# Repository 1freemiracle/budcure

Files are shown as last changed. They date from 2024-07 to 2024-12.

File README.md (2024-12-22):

# The Cannaster reinvisions the post-harvest workflow. The BudCureBox and Cannaster allows for automated control over the moisture content of the harvest, promising distinct differences in auroma and flavor. 

<div align="center">
BudCure machines
BudCure machines
</div>

## In the BudCureBox, you can estimate the moisture content by the weight loss due to evaporation. The weight is tracked from harvest and a target weight is calculated. This weight is used to know when to take the nugs off the branch and put into the Cannaster, when about 65% of the initial weight is lost.

<div align="center">
Inside BudCure Box
</div>

> The BudCure Box provides a stable environment for the buds to slowly dry. 

## The Cannaster takes mostly dry nugs and gets them to the perfect moisture content for canning. The vacuum brings moisture out from inside the nugs, drying them quickly and evenly to a precise moisture content. 

<div align="center">
inside the Cannaster
</div>
> The Cannaster dials in the moisture content of the buds in preparation for canning.

## The machines are built out of laser cut or 3D printed parts, and I have included up to date files on how to build one, including eagle PCB and fusion 360 files.

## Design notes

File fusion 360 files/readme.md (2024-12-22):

# Files for the 3D printed parts and laser cut panels. 
## Fusion 360 was used for the design work



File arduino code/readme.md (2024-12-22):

## The BudCure Box and Cannaster programs use a rotary encoder and OLED display to interact with users. 
# The BudCure Box and Cannaster use the Wemos D1 mini, and your able to connect to them on your phone via wifi.

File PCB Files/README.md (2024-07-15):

# EAGLE CAD FILES
## The BudCure Box and Cannaster utilize the Arduino Nano.

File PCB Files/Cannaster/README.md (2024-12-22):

# PCB files for the Cannaster
## 4 stepper motors plug directly into the board, with the L293D stepper driver chip. I'm also plugging into i2c humidity and pressure sensor, the BMP280 + AHT20, along with an OLED with rotary encoder display. The cannaster is powered by the wemos d1 mini. 
PCB rendering

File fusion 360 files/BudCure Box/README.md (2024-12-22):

door open
# The BudCure Box uses
##  laser cut panels and 3D printed parts. The box panels are held together with 3D printed slots bolted to the adjacent panel. One major design consideration is that the box has to be sealed from the outside humidity, so extra steps are taken to provide a sealed interior. The display is on the front door, and all the electronics are on the roof. The buds hang upside down from the load cell. There is a removable rack for loading the buds into the machine, I desgned some clips to hold the stems under spring pressure. It is designed to hold up to 1800 grams. 
Some design issues that have arrisen is that the rack is very sensitive, so all the wires above it had to be tied down. Also, the wires for the display limit the amount of travel of the door.

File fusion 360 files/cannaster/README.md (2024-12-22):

# Welcome to the Cannaster 
##

cannaster

The Cannaster is simple to build. The lid is the most complex part of the process, requiring a good enough seal to reach below 7psi. It has one port to accept 4 wires (to the i2c sensors) and a vacuum line. I have to use epoxy to seal the inside of the lid. The gasket that seals the baine marie to the lid is made from pourable silicon. The gasket is poured directly into the lid. The lid is driven by 4 stepper motors, turning a screw with just enough torque to push down the lid for a good enough seal to start pressurizing the pot. 

The baine marie has an insert that helps keep the buds seperated, made from extruded plexiglass and cut on the laser cutter.

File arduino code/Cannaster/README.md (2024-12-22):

# The Cannaster
## Super convenient way to get nugs to the perfect moisture content for canning
The cannaster uses a combination pressure, humidity, and temperature sensor to monitor the conditions inside the baine marie. A voltage converter converts the 3.3v of the D1 mini to 5v that the L293D chip uses to drive the stepper motors. 
### The Cannaster currently uses a timer to turn on the pump, and also a maximum rh level. So that you can set the pump to come on every 1.5 hours and the rh set at 80%, then the pump will turn on less and less until it only turns on every 1.5 hours. The cannaster also uses wifi to display data about the current drying states (well displaying it is a work in progress, but you can download the data from the sensors).

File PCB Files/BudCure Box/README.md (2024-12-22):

# PCB for the BudCure Box
## The BudCure Box pcb utilizes two mosfets, OLED/rotary encoder, i2c humidity sensor, load cell (with hx711), and a one wire temperature sensor for the TEC. 12V power runs the TEC and the fan while a 5v regulator supplies the Wemos. 
pcb image

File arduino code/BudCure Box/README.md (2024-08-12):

# The BudCure Box program files (Arduino IDE)
## The BudCure uses two mosfets to switch the thermoelectric device `TEC` and the exauhst fan. It reads from two sensors, one is a temperature probe (one wire 'dallas temperature sensor') plugged into the TEC, and a 'DHT22' temp/humidity sensor. I'm using a 'WEMOS D1 MINI' for the processor, using every pin except A0 (the single analog pin). I'm using interrupts to manage the rotary encoder with integrated pushbutton. Memory is also used to record various data.
To make the load cell more accurate (due to drift of the readings) I implimented a scheme where you remove the tray to tare out the drift and then replace the tray to get the correct weight readings. 
### Using the OLED display and the rotary encoder you can scroll through several options. You start with calibrating the scale (without the tray attached) with the calibrate option. That option puts in the weight of the tray into memory. You would then load up the tray with plant material and then use option "new weight" to record the starting initial wieght into memory. Then you would turn on either the fan or the TEC to keep the humidity down. As the material dries you keep recording new weights to track moisture loss.

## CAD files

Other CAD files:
fusion 360 files/cannaster/Arduinana_finale v42.f3z

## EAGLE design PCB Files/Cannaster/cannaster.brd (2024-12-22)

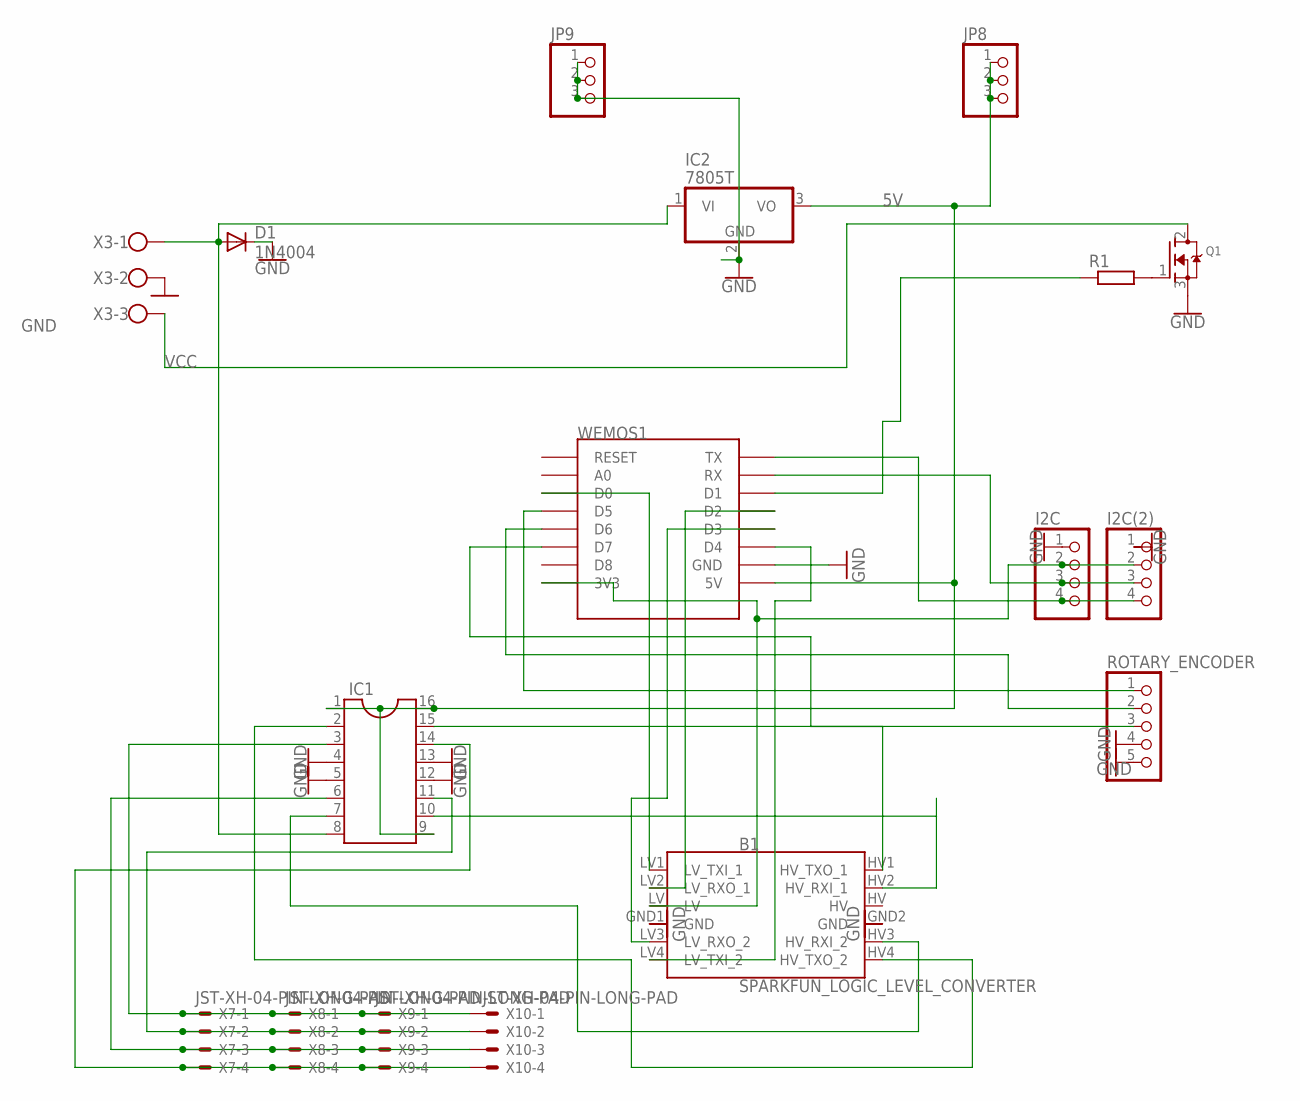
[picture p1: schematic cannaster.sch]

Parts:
B1: SPARKFUN_LOGIC_LEVEL_CONVERTER
D1: 1N4004; DO41-10
I2C, I2C(2): PINHD-1X4; 1X04
IC1: DIL16
IC2: 7805T; TO220H
JP8, JP9: PINHD-1X3; 1X03
Q1: MOSFET-NGDS_TO220V; TO220V
R1: R-EU_0207/7; 0207/7
ROTARY_ENCODER: PINHD-1X5; 1X05
WEMOS1: WEMOS-D1-MINI
X3: W237-103
X7, X8, X9, X10: JST-XH-04-PIN-LONG-PAD; JST-XH-04-PACKAGE-LONG-PAD

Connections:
5V: IC1.1, IC1.9, IC1.16, IC2.3 (VO), JP8.1, JP8.2, JP8.3, WEMOS1.5V
GND: B1.GND1 (GND), B1.GND2 (GND), D1.C, I2C.1, I2C(2).1, IC1.4, IC1.5, IC1.12, IC1.13, IC2.2 (GND), JP9.1, JP9.2, JP9.3, Q1.3 (S), ROTARY_ENCODER.4, ROTARY_ENCODER.5, WEMOS1.GND, X3.2
HV: B1.HV
unnamed: IC1.3, X7.1, X8.1, X9.1, X10.1
unnamed: IC1.11, X7.2, X8.2, X9.2, X10.2
unnamed: B1.HV1 (HV_TXO_1), IC1.15
unnamed: IC1.14, X7.4, X8.4, X9.4, X10.4
unnamed: B1.LV1 (LV_TXI_1), WEMOS1.D0
unnamed: Q1.2 (D), X3.3
unnamed: I2C.4, I2C(2).4, WEMOS1.TX
unnamed: I2C.3, I2C(2).3, WEMOS1.RX
unnamed: B1.LV2 (LV_RXO_1), WEMOS1.D2
unnamed: Q1.1 (G), R1.2
unnamed: B1.LV3 (LV_RXO_2), WEMOS1.D3
unnamed: B1.LV4 (LV_TXI_2), WEMOS1.D4
unnamed: ROTARY_ENCODER.1, WEMOS1.D5
unnamed: ROTARY_ENCODER.2, WEMOS1.D6
unnamed: ROTARY_ENCODER.3, WEMOS1.D7
unnamed: R1.1, WEMOS1.D1
unnamed: B1.LV, I2C.2, I2C(2).2, WEMOS1.3V3
unnamed: B1.HV2 (HV_RXI_1), IC1.10
unnamed: B1.HV3 (HV_RXI_2), IC1.7
unnamed: B1.HV4 (HV_TXO_2), IC1.2
unnamed: IC1.6, X7.3, X8.3, X9.3, X10.3
VCC: D1.A, IC1.8, IC2.1 (VI), X3.1

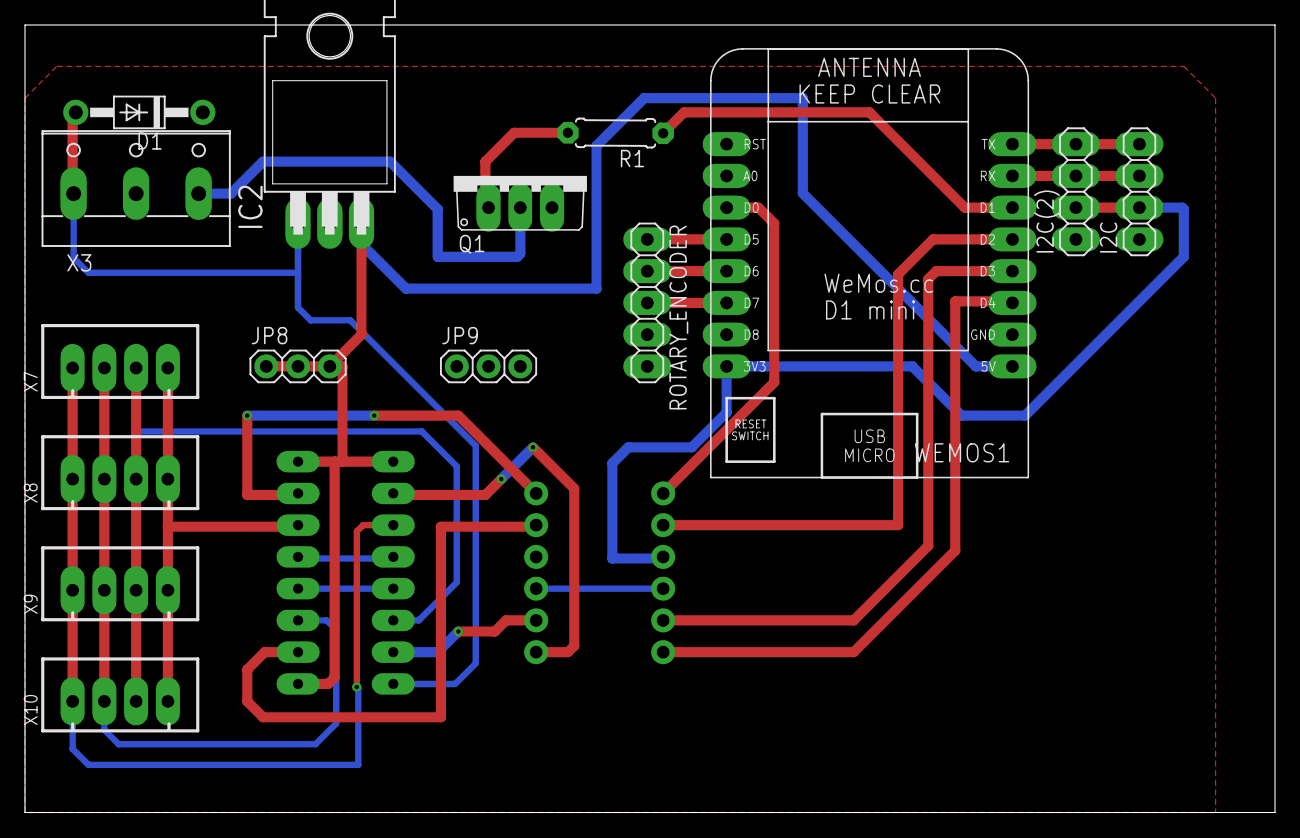
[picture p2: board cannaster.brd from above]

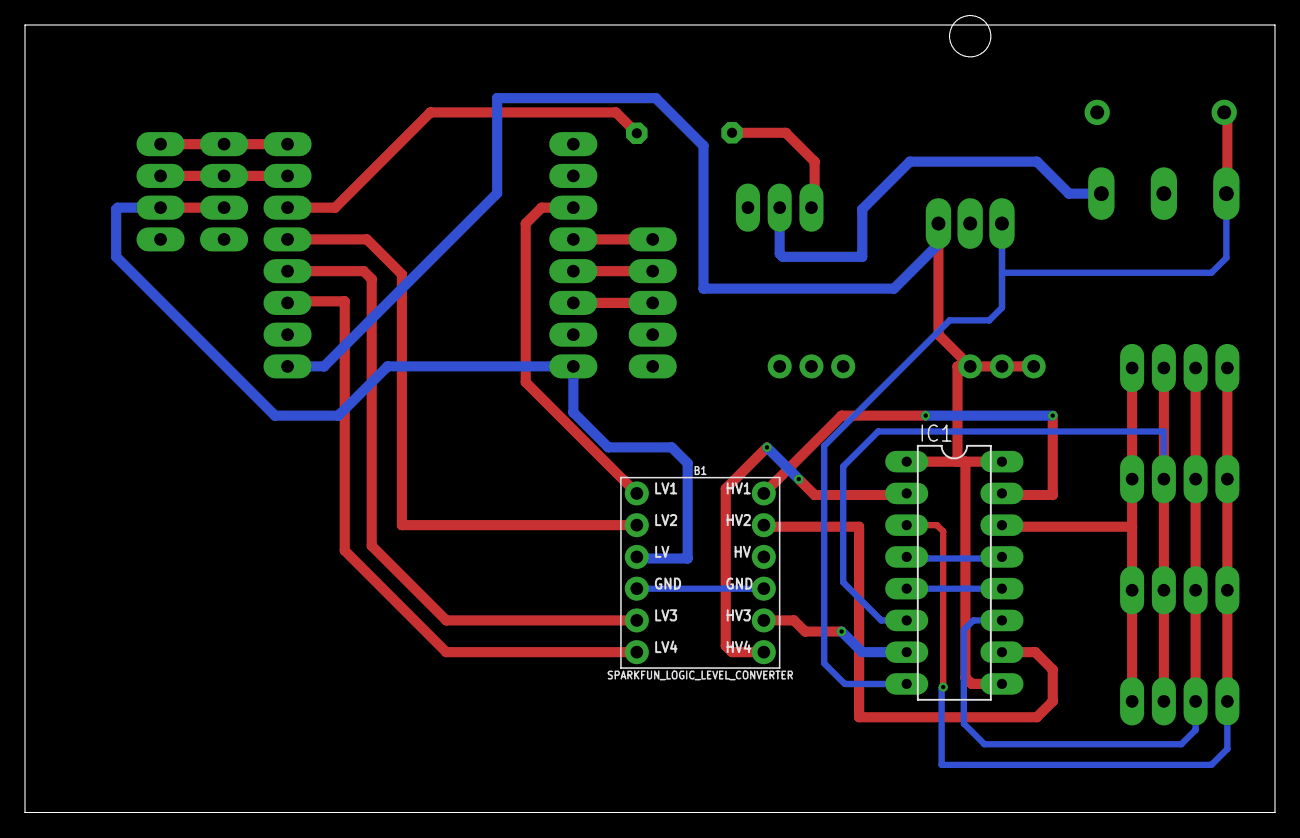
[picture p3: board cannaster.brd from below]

Board: 2 copper layers, 100.0 x 63.0 mm, 17 parts (2 on the bottom side), 24 nets.

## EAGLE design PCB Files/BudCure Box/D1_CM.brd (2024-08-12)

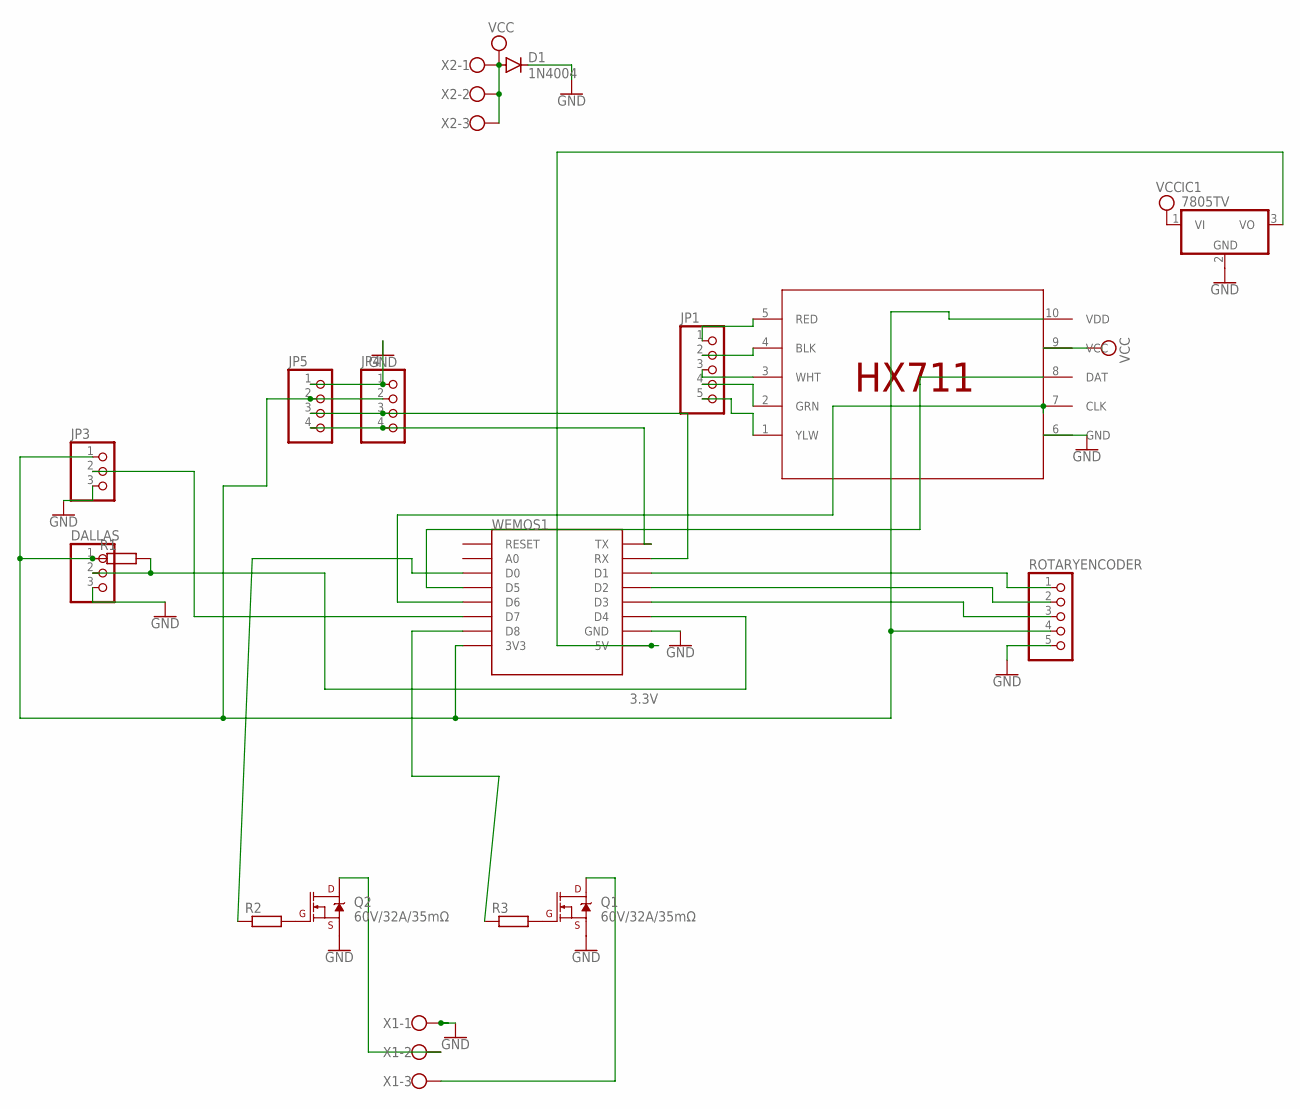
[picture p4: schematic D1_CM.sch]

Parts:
D1: 1N4004; DO41-10
DALLAS: PINHD-1X3; 1X03
IC1: 7805TV; TO220V
JP1: PINHD-1X5; 1X05
JP3: PINHD-1X3; 1X03
JP4, JP5: PINHD-1X4; 1X04
Q1, Q2: 60V/32A/35mΩ; TO220V
R1, R2, R3: R-EU_0207/7; 0207/7
ROTARYENCODER: PINHD-1X5; 1X05
U$1: DEVICY; FOOTSY
WEMOS1: WEMOS-D1-MINI
X1, X2: W237-103

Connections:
3.3V: DALLAS.1, JP3.1, JP4.2, JP5.2, R1.1, ROTARYENCODER.4, U$1.10 (VDD), WEMOS1.3V3
GND: D1.C, DALLAS.3, IC1.2 (GND), JP3.3, JP4.1, JP5.1, Q1.3 (S), Q2.3 (S), ROTARYENCODER.5, U$1.6 (GND), WEMOS1.GND, X1.1
unnamed: JP1.1, U$1.5 (RED)
unnamed: JP1.2, U$1.4 (BLK)
unnamed: JP1.3, U$1.3 (WHT)
unnamed: JP1.4, U$1.2 (GRN)
unnamed: JP1.5, U$1.1 (YLW)
unnamed: DALLAS.2, R1.2, WEMOS1.D4
unnamed: Q2.1 (G), R2.2
unnamed: JP4.3, JP5.3, WEMOS1.RX
unnamed: JP4.4, JP5.4, WEMOS1.TX
unnamed: Q1.1 (G), R3.2
unnamed: ROTARYENCODER.2, WEMOS1.D2
unnamed: ROTARYENCODER.1, WEMOS1.D1
unnamed: R2.1, WEMOS1.D0
unnamed: R3.1, WEMOS1.D8
unnamed: Q2.2 (D), X1.2
unnamed: Q1.2 (D), X1.3
unnamed: U$1.8 (DAT), WEMOS1.D5
unnamed: U$1.7 (CLK), WEMOS1.D6
unnamed: JP3.2, WEMOS1.D7
unnamed: ROTARYENCODER.3, WEMOS1.D3
unnamed: IC1.3 (VO), WEMOS1.5V
VCC: D1.A, IC1.1 (VI), U$1.9 (VCC), X2.1, X2.2, X2.3

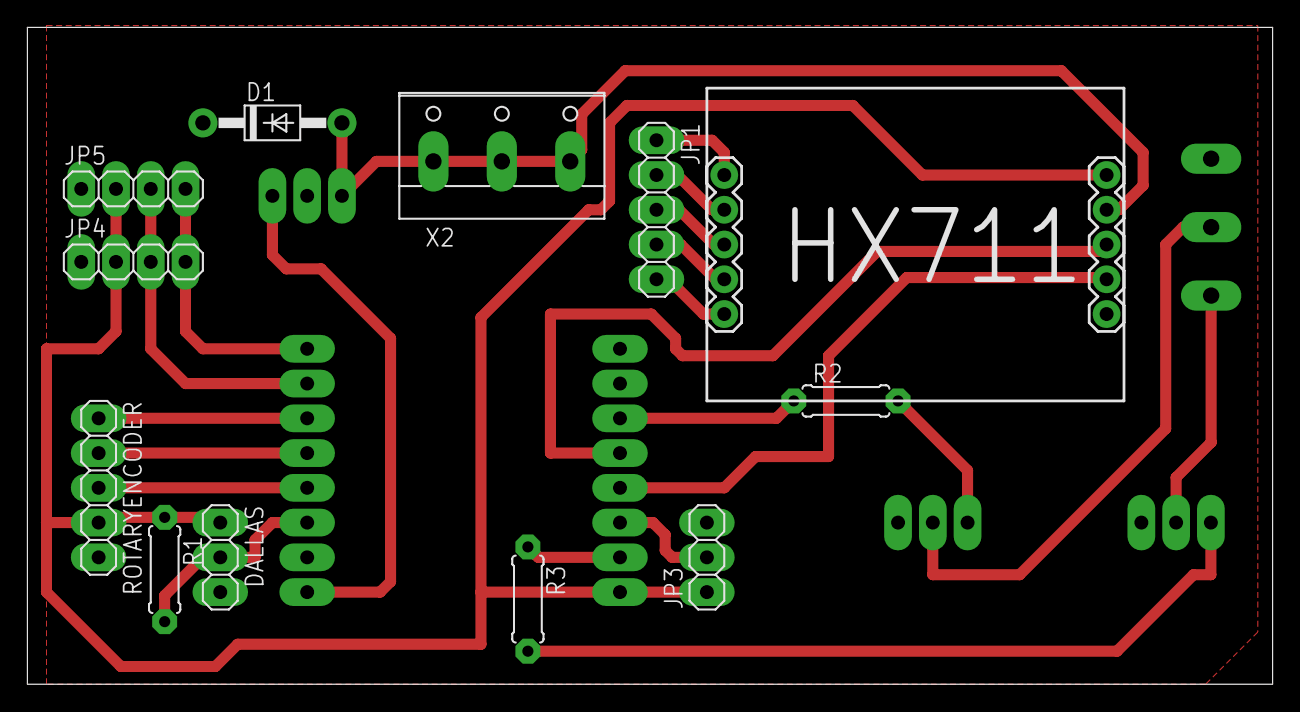
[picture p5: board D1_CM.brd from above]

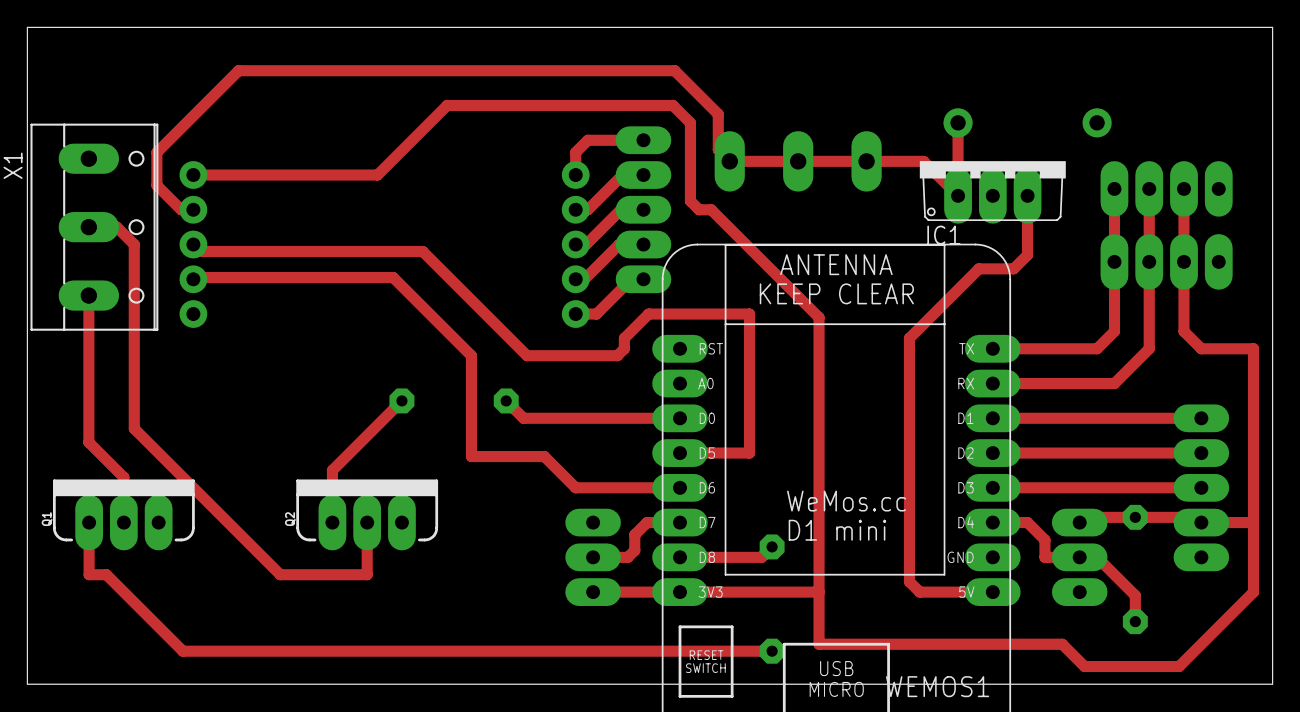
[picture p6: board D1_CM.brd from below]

Board: 2 copper layers, 91.0 x 48.0 mm, 17 parts (5 on the bottom side), 24 nets.

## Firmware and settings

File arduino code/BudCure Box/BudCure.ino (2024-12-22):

#include <Wire.h>              
#include "SSD1306Wire.h"       
#include <OneWire.h>
#include <DallasTemperature.h>
#include "ESPRotary.h"
#include "Ticker.h"
#include "DHT_Async.h"
#include <HX711_ADC.h>
#include <EEPROM.h>
#include <ESP8266WiFi.h>
#include <ESP8266WebServer.h>
#include <FS.h>  

#define DHT_SENSOR_TYPE DHT_TYPE_22
#define DHT_SENSOR_PIN D7
#define ROTARY_PIN1 D2
#define ROTARY_PIN2 D1
#define ENCODER_SWITCH_PIN D3
#define ONE_WIRE_BUS D4
#define FAN_PIN 16
#define TEC_PIN 15
#define HX711_dout D5 
#define HX711_sck D6
////////////////////////////////////////////////////////server
const char* targetSSID = "G8X"; // Your Wi-Fi SSID
const char* password = "6669inchs"; // Replace with your Wi-Fi password
ESP8266WebServer server(80);

////////////////////////////////////////////////////////loadcell
#define CALIBRATE_ADDRESS 0 //STATIC
#define TARE_ADDRESS 10 //STATIC
#define TRAY_ADDRESS 20 //STATIC
#define FANPROGRAM_ADDRESS 30 //booleen
#define TECPROGRAM_ADDRESS 32 //booleen
#define FANCYCLE_ADDRESS 35 //STATIC
#define FANDURATION_ADDRESS 40 //STATIC 
#define HUMIDITY_ADDRESS 45 //STATIC
#define FROSTY_ADDRESS 50 //STATIC
#define EVENT_ADDRESS 100 //DECIMAL NUMBER
#define TEMP_ADDRESS 300 //STORES AN ARRAY
#define WEIGHT_ADDRESS 200 //STORES AN ARRAY
float calibrationValue; 
int eventCount = 0; //track how many elements are in the weights array

DHT_Async dht_sensor(DHT_SENSOR_PIN, DHT_SENSOR_TYPE);
/////////////////////////////////////////////////////////Rotary Encoder
#define CLICKS_PER_STEP 2
#define MIN_POS         0
#define MAX_POS         10
#define START_POS       1
#define INCREMENT       1   
ESPRotary r;
Ticker t;
bool updateHomeScreen = false;  // Flag to trigger home screen update
/////////////////////////////////////////////////////////////Display
SSD1306Wire *display;

OneWire oneWire(ONE_WIRE_BUS);
DallasTemperature sensors(&oneWire);
DeviceAddress insideThermometer = { 0x28, 0x2E, 0x50, 0x57, 0x04, 0xE1, 0x3C, 0x42 };
HX711_ADC LoadCell(HX711_dout, HX711_sck);
/////////////////////////////////////////////////////////////////Weight Program
float loadData; //value from getData()
float trayWeight;
long storedTareValue; 
float weights[99]; 
float temps[99];
float weight;
//////////////////////////////////////////////////////////////////Sensor Data
float temperature; //temp of the box
float humidity;
float humidityThresholdOn = 75.0;  // Humidity level to turn the fan on
float humidityThresholdOff = 65.0; // Humidity level to turn the fan off
float tempC; //temp of the probe
bool flagData = true;
unsigned long seconds;
unsigned long minutes;
unsigned long hours;
//////////////////////////////////////////////////////Rotary Program
volatile bool interruptFlag = false; 
int lastPosition = 1; 
bool moved = false;
int position = 1; //position of the rotary encoder
int debounce = 50; //for the encoder pushbutton

void IRAM_ATTR handleInterrupt() {
  interruptFlag = true;
}
/////////////////////////////////////////////////////////////////////////////////////////////////////////////programs
int fanCyclesPerHour = 4; // Fan turns on this many times per fanCycleInterval
int fanOnDuration;   // length of time in seconds the fan stays on
int fanStartMinute = 0;  // Variable to store the minute when the fan was turned on
int fanCycleInterval;   // Used to calculate time inbetween fan starts
float humidities;
float frosty = -10;
int pwmTec = 0; // for setting the tec mosfet 
///////////////////////////////////////////////////////////////////////////////////////////////////////////////routing 
bool fanGram = false; //toggles in fan display so to keep the fanProgram current in the loop, saved to eeprom in case of reset
bool fanState = false; //used in fan program
bool tecGram = false;

const int MAX_DEVICES = 10;
String devicesOn[MAX_DEVICES];
int deviceCount = 0;

float dewPoint;

void setup() {
  pinMode(1, FUNCTION_3);
  pinMode(3, FUNCTION_3);
  pinMode(ENCODER_SWITCH_PIN, INPUT_PULLUP);
  pinMode(FAN_PIN, OUTPUT);
  pinMode(TEC_PIN, OUTPUT);
  attachInterrupt(digitalPinToInterrupt(ENCODER_SWITCH_PIN), handleInterrupt, FALLING);
  //display
  display = new SSD1306Wire(0x3c, 1, 3);
  display->init();
  display->flipScreenVertically();
  display->setFont(ArialMT_Plain_10);
  //Dallas TEMP sensor
  sensors.begin();
  //Rotary encoder
  r.begin(ROTARY_PIN1, ROTARY_PIN2, CLICKS_PER_STEP, MIN_POS, MAX_POS, START_POS, INCREMENT);
  r.setChangedHandler(rotate);
  r.setLeftRotationHandler(showDirection);
  r.setRightRotationHandler(showDirection);
  t.attach_ms(10, handleLoop);

  SPIFFS.begin();

  EEPROM.begin(512);
  EEPROM.get(TARE_ADDRESS, storedTareValue);
  EEPROM.get(CALIBRATE_ADDRESS, calibrationValue);

  LoadCell.begin();
  unsigned long stabilizingtime = 2000; 
  boolean _tare = false; //set this to false if you don't want tare to be performed in the next step
  LoadCell.start(stabilizingtime, _tare);

  LoadCell.setTareOffset(storedTareValue);
  LoadCell.setCalFactor(calibrationValue);

  LoadCell.update();
  LoadCell.refreshDataSet();

  EEPROM.get(EVENT_ADDRESS, eventCount);
  EEPROM.get(TRAY_ADDRESS, trayWeight);
  loadWeights(); //FROM EEPROM

  WiFi.mode(WIFI_STA); // Set Wi-Fi mode to Station 

  server.on("/", handleRoot);
  server.on("/setVariables", HTTP_POST, handleSetVariables);
  server.on("/data", handleData);
  server.on("/list", handleFileList); 
  server.on("/download", handleDownload);

  EEPROM.get(FANPROGRAM_ADDRESS, fanGram);
  EEPROM.get(FANDURATION_ADDRESS, fanOnDuration);
  EEPROM.get(FANCYCLE_ADDRESS, fanCyclesPerHour);
  EEPROM.get(TECPROGRAM_ADDRESS, tecGram);
  EEPROM.get(HUMIDITY_ADDRESS, humidities);
  EEPROM.get(FROSTY_ADDRESS, frosty); 

  if (fanGram) {addDevice("FAN");}
  if (tecGram) {addDevice("TEC");}
  if (!fanCyclesPerHour) {fanCyclesPerHour = 1;}

}


void loop() {
  position = r.getPosition();
  sensors.requestTemperatures();
  tempC = sensors.getTempC(insideThermometer);
  dht_sensor.measure(&temperature, &humidity);
  dewPoint = (temperature - ((100 - humidity) / 5)) - 15;
  if (LoadCell.update()) {
      loadData = LoadCell.getData();
      weight = loadData - trayWeight;
  }
  if (minutes != 0 && (minutes % 5 == 0) && flagData) { 
      logData("data.csv"); 
      flagData = false;  // Prevent further logging in the same 15-minute window
      if (tecGram) {
        logData("data2.csv");
      }
  } 
  else if (minutes % 5 != 0 && !flagData) { 
      flagData = true;  // Reset flag when not in a 15-minute interval
  }
  ///////////////////////////////////////////////////////////////////////////////////////////////////////////////////
  //                                    Encoder Button
  ///////////////////////////////////////////////////////////////////////////////////////////////////////////////////
  if (interruptFlag) {
    delay(debounce);
    switch(position) {
      case 1: 
        wifiScreen();
        break;
      case 2:
        addDevice("TEC");
        tecScreen();
        break;
      case 3:
        newWeightScreen();
        break;
      case 4:
        memoryScreen();
        break;
      case 5:
        resetScreen();
        break;
      case 6:
        calibrationScreen();
        break;
      case 7:
        tareScreen();
        break;
      case 8:
        weightScreen();
        break;
      case 9:
        addDevice("FAN");
        fanScreen();
        break;
        
    }
    
  } 
  //////////////////////////////////////////////////////////////////////////////////////////////////////////////////////
  //                            routing
  //////////////////////////////////////////////////////////////////////////////////////////////////////////////////////
  switch (position) {
    case 1: 
      homeScreen();
      break;
  }

  if (moved) {
    moved = false;
    if (position > 1) {
      selectionScreen(position);
    }
  }

  if(tecGram) {
    tecProgram();
  } else {
      removeDevice("TEC");
      digitalWrite(TEC_PIN, LOW);}

  if (fanGram) {
    fanProgram();
  } else {
    removeDevice("FAN");
    digitalWrite(FAN_PIN, LOW);}
  

  ////////////////////////////////////////////////////////////////////////////////////////////////////////////////
  //                              CLOCK
  ///////////////////////////////////////////////////////////////////////////////////////////////////////////////

  unsigned long timeElapsed = millis() / 1000;  // Convert to seconds directly
  seconds = timeElapsed % 60;  // Keep seconds [0-59]
  minutes = (timeElapsed / 60) % 60;  // Keep minutes [0-59]
  hours = (timeElapsed / 3600);  // Calculate hours

}

///////++++++++++++++++++++++++++++++++++++++++++++++++++++++++++++++++++++++++++++++++++++++++++++++++++++++++++++++++++++++++++++++++++++++++++++++++++++++++++++++++++++++++++++++++++++++++++++++++++++++++++++++++++++++++++++++++

void selectionScreen(int position) {
    const char* options[] = {
  "nanner",
  "Home",
  "TEC",
  "New Weight",
  "Memory",
  "Reset",
  "Calibration",
  "Tare",
  "weight",
  "fan"
  };

  int y = 20;
  int x = 20;
  display->clear();
  for (int i = 2; i < 10; i++) {
    if (i < 6) {
    if (i == position) {
      display->fillRect(0, y, 64, 12);  // Highlight background
      display->setColor(BLACK);
      display->setTextAlignment(TEXT_ALIGN_LEFT);
      display->drawString(0, y, options[i]);  // Highlighted text
      display->setColor(WHITE);
    } else {
      display->setTextAlignment(TEXT_ALIGN_LEFT);
      display->drawString(0, y, options[i]);  // Normal text
    }
    y += 10;
    } else {
      if (i == position) {
      display->setTextAlignment(TEXT_ALIGN_RIGHT);
      display->fillRect(64, x, 128, 12);  // Highlight background
      display->setColor(BLACK);
      display->drawString(128, x, options[i]);  // Highlighted text
      display->setColor(WHITE);
    } else {
      display->setTextAlignment(TEXT_ALIGN_RIGHT);
      display->drawString(128, x, options[i]);  // Normal text
    }
    x += 10;
    }

    
  }
  display->display();

}

void logData(const char* filename) {
    // Check which file to save to based on the keyword
  if (strcmp(filename, "data.csv") == 0) {
   if (!SPIFFS.exists("/data.csv")) {
      File file = SPIFFS.open("/data.csv", "w");  // Create a new file
      if (!file) {
        return;
      }
      // Write the headers
      file.println("Temperature,Humidity,Weight");
      file.close();
    }

    // Open the file for appending the data
    File file = SPIFFS.open("/data.csv", "a");
    if (!file) {
      return;
    }

    file.print(temperature);
    file.print(",");
    file.print(humidity);
    file.print(",");
    file.println(weight);

    file.close();  // Close the file
  } 
  else if (strcmp(filename, "data2.csv") == 0) {
    if (!SPIFFS.exists("/data2.csv")) {
      File file = SPIFFS.open("/data2.csv", "w");  // Create a new file
      if (!file) {
        return;
      }
      // Write the headers
      file.println("probe,box,humidity");
      file.close();
    }

    // Open the file for appending the data
    File file = SPIFFS.open("/data2.csv", "a");
    if (!file) {
      return;
    }

    // Write temperature and humidity data in CSV format
    file.print(tempC);
    file.print(",");
    file.print(temperature);
    file.print(",");
    file.println(humidity);

    file.close();  // Close the file
  } 
  else {
    return; // Exit if the file is not recognized
  }
  
}

static bool measure_environment(float *temp, float *humidity) {
    static unsigned long measurement_timestamp = millis();

    /* Measure once every four seconds. */
    if (millis() - measurement_timestamp > 4000ul) {
        if (dht_sensor.measure(temp, humidity)) {
            measurement_timestamp = millis();
            return (true);
        }
    }

    return (false);
}

void addDevice(String deviceName) {
    if (deviceCount < MAX_DEVICES) {
        devicesOn[deviceCount] = deviceName;
        deviceCount++;
    } else {
        Serial.println("Device limit reached!");
    }
}

void removeDevice(String deviceName) {
    for (int i = 0; i < deviceCount; i++) {
        if (devicesOn[i] == deviceName) {
            // Shift remaining devices to fill the gap
            for (int j = i; j < deviceCount - 1; j++) {
                devicesOn[j] = devicesOn[j + 1];
            }
            devicesOn[deviceCount - 1] = "";  // Clear last entry
            deviceCount--;
            break;
        }
    }
}

bool isDeviceOn(String deviceName) {
    for (int i = 0; i < deviceCount; i++) {
        if (devicesOn[i] == deviceName) {
            return true;
        }
    }
    return false;
}

void displayDevicesOn() {
    display->setTextAlignment(TEXT_ALIGN_LEFT);

    if (deviceCount == 0) {
        display->drawString(0, 54, "None");
    } else {
        // Loop through the devices that are currently on and display them
        for (int i = 0; i < deviceCount; i++) {
            display->drawString(i * 16, 54, devicesOn[i]);
        }
    }
  return;
}

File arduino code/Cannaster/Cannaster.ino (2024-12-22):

#include <Wire.h>          
#include <ESP8266WiFi.h> 
#include <ESP8266WebServer.h>   
#include <SSD1306Wire.h>  
#include <ESPRotary.h>
#include <Ticker.h>
#include <Adafruit_Sensor.h>
#include <Adafruit_BME280.h>
#include "FreeMonoBold12pt7b.h"
#include <EEPROM.h>
#include <Stepper.h>

////////////////////////////////////////////////////////server
const char* targetSSID = "G8X"; // Your Wi-Fi SSID
const char* password = "6669inchs"; // Replace with your Wi-Fi password
ESP8266WebServer server(80);

Adafruit_BME280 bme; // I2C
//#define MINUTES_TO_MILLISECONDS(minutes) ((minutes) * 60UL * 1000UL)
#define HOURS_TO_MILLISECONDS(hours)     ((hours) * 60UL * 60UL * 1000UL) 
#define MAX_ADDRESS 0
#define PRESS_ADDRESS 5
#define GO_ADDRESS 10
#define DELAY_ADDRESS 15
#define HUMIDITY_ADDRESS 20
const int stepsPerRevolution = 4060;
const int steps = (stepsPerRevolution/360) * 22;
Stepper myStepper(stepsPerRevolution, D0, D2, D3, D4);
#define relayPin D1
#define ROTARY_PIN1 D5
#define ROTARY_PIN2 D6
#define ENCODER_SWITCH_PIN D7
#define EEPROM_SIZE 4096 

#define CLICKS_PER_STEP 4
#define MIN_POS         0
#define MAX_POS         7
#define START_POS       1
#define INCREMENT       1   
#define SPEEDUP_STEPS   2
ESPRotary r;
Ticker t;
SSD1306Wire *display;
//////////////////////////////////         Rotary Program
volatile bool interruptFlag = false; 
int lastPosition = 1; 
bool moved = false;
int position = 1; 
int debounce = 125; 
///////////////////////////////////        STEPPER MOTOR
int stepsToMove = 375;
int currentStep = 0;
///////////////////////////////////        INTERRUPT
unsigned long x = 0;
void IRAM_ATTR handleInterrupt() {
  if (millis() - x > 1250) {
    interruptFlag = true;
    x = millis();
  }
}
///////////////////////////////////        PROGRAM GO SETUP
int humidityThreshold = 30; 
int pressureThreshold = 5;
unsigned long prgDelay = HOURS_TO_MILLISECONDS(1.5); 
bool enablePrg = true;
bool disablePmp = false;
bool programGo = false;
bool isVacuumOn = false;
unsigned long prgOffTime; 
unsigned long prgStartTime;
unsigned long seconds;
unsigned long minutes;
int maxHumidity = 80;
float humidity;
float pressure;
float psi;
float temperature;
///////////////////////////////////        TIMING FOR MAIN DISPLAY AND SENSOR DATA
int dataLoad = 500; 
unsigned long lastDataReload = 0; 
///////////////////////////////////        EEPROM RECORDING HUMIDITY VALUES DATA POINTS 
static unsigned int lastRecordedMinute = 0;
static int eepromAddress = HUMIDITY_ADDRESS + 10;  
///////////////////////////////////        SPEEDUP FEATURE OF MOTORIZED LID

void setup() {
  pinMode(1, FUNCTION_3);
  pinMode(3, FUNCTION_3);
  pinMode(ENCODER_SWITCH_PIN, INPUT_PULLUP);
  pinMode(relayPin, OUTPUT);
  pinMode(D0, OUTPUT);
  pinMode(D4, OUTPUT);
  pinMode(D2, OUTPUT);
  pinMode(D3, OUTPUT);
  digitalWrite(relayPin, LOW);
  attachInterrupt(digitalPinToInterrupt(ENCODER_SWITCH_PIN), handleInterrupt, FALLING);

  // Display
  Wire.begin(1, 3); //Join I2C bus
  display = new SSD1306Wire(0x3c, 1, 3);
  display->init();
  display->flipScreenVertically();
  display->setFont(ArialMT_Plain_16);  // Set font size
  display->drawString(8, 0, "cannaster dude");
  display->display();
  delay(500);
  unsigned status;
  bme.begin(0x76);
  
  // Rotary encoder
  r.begin(ROTARY_PIN1, ROTARY_PIN2, CLICKS_PER_STEP, MIN_POS, MAX_POS, START_POS, INCREMENT);
  r.setChangedHandler(rotate);
  r.setLeftRotationHandler(showDirection);
  r.setRightRotationHandler(showDirection);
  t.attach_ms(3, handleLoop);
  
  // EEPROM
  EEPROM.begin(EEPROM_SIZE);
  EEPROM.get(MAX_ADDRESS, maxHumidity);
  EEPROM.get(GO_ADDRESS, programGo);
  EEPROM.get(DELAY_ADDRESS, prgDelay);
  EEPROM.get(HUMIDITY_ADDRESS, eepromAddress);
  EEPROM.get(PRESS_ADDRESS, pressureThreshold);

  // STEPPER
  myStepper.setSpeed(7);
  digitalWrite(D0, LOW);
  digitalWrite(D2, LOW);
  digitalWrite(D3, LOW);
  digitalWrite(D4, LOW);

  WiFi.mode(WIFI_STA); // Set Wi-Fi mode to Station 
  server.on("/", handleRoot);
  server.on("/setVariables", HTTP_POST, handleSetVariables);
  server.on("/data", handleData);
  server.on("/list", handleFileList); 
  server.on("/download", handleDownload);
}

void loop() {
  // ENCODER BUTTON
  if (interruptFlag) {
    delay(debounce);
    interruptFlag = false;
    handleButton(position);
  }
  // TIMED SENSOR UPDATES + UPDATING THE OLED SCREEN
  if ((millis() - lastDataReload) > dataLoad) {
    measurements();
    if (position == 1) {
      displaySensorReadings();
    }
    lastDataReload = millis();
  }
  // WORKING THE ENCODER DIAL ON INTERRUPT
  if (moved) {
    delay(debounce);
    moved = false;
    handleEncoder(position);
  }
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

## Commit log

2024-07-14 Create Arduino Code
2024-08-12 Create encoder_functions
2024-12-22 Update encoder_functions

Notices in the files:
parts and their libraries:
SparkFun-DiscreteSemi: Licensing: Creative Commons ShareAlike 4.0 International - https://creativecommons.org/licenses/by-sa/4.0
